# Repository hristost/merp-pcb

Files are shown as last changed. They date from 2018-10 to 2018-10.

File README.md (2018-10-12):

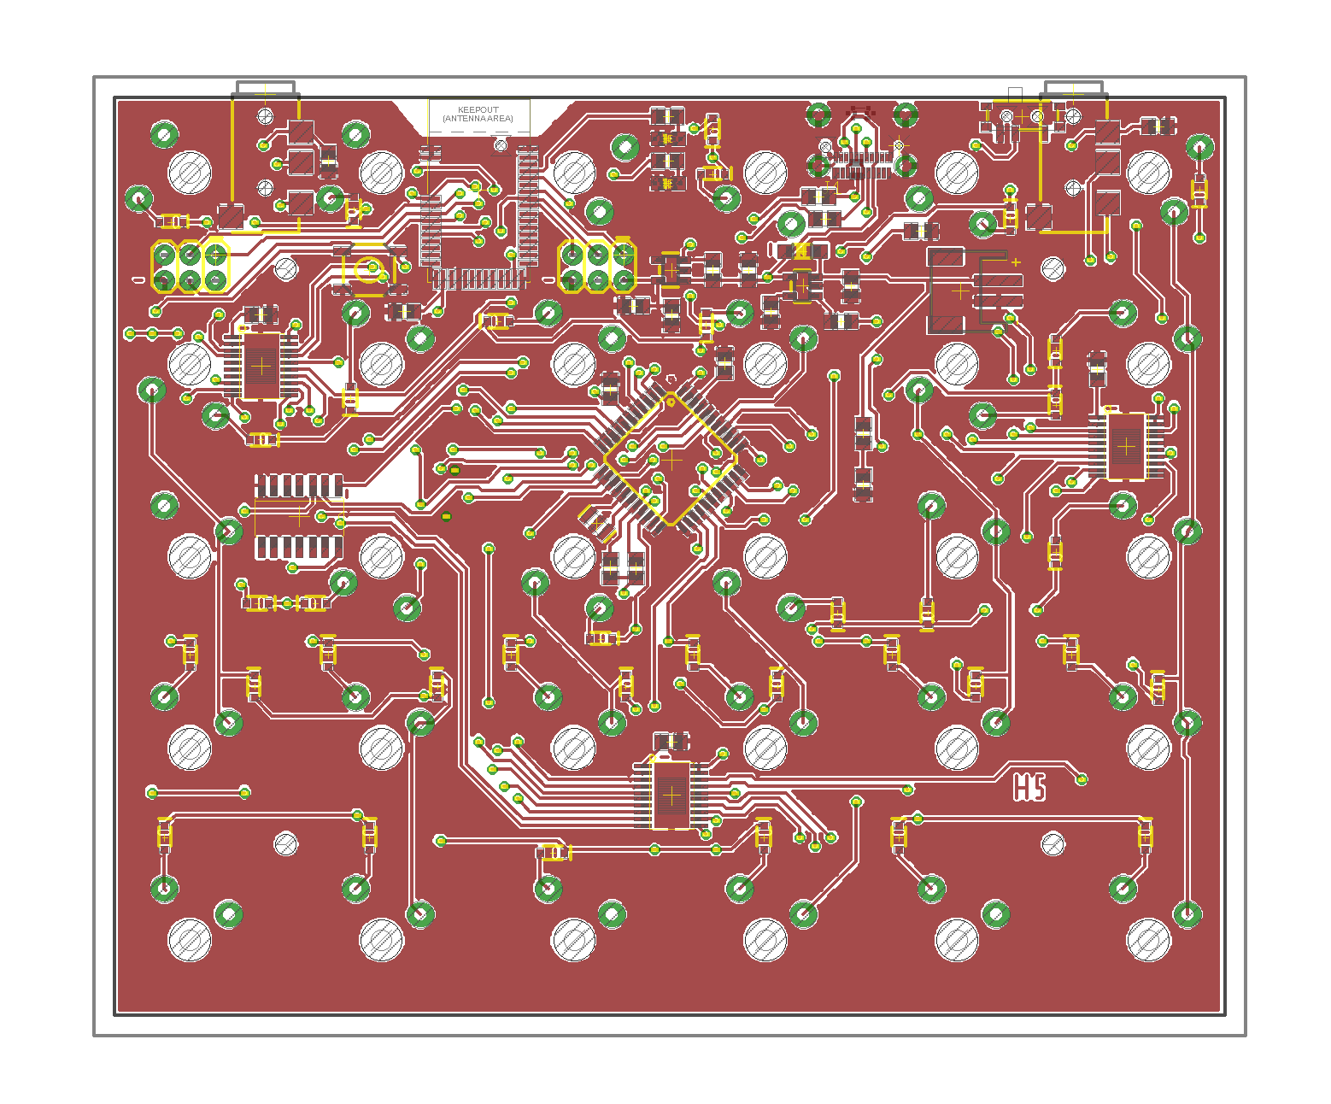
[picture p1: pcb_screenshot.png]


This is a PCB for a bluetooth split 12x5 ortholinear keyboard:
* Based on Adafruit's 32u4 
[Feather](https://github.com/adafruit/Adafruit-Feather-32u4-Bluefruit-LE-PCB)
beard. 
* Wireless (BLE) and wired (USB-C) mode.
* LED backlight.
* There are two 6x2 halves with identical PCBs. The _master_ half runs the QMK
firmware, and handles USB, BLE and battery charging. The _slave_ half is
responsible for only reporting its state to _master_ over I2C.
* Extra TRRS jack on the _slave_ half, making it possible to chain other I2C 
peripherals (think pedals).
* The board is flashed with the QMK firmware -- see my
[fork](https://github.com/hristost/qmk_firmware/tree/hristost_merp/keyboards/merp)
.

## Bluetooth
The PCB uses the Raytac MDBT-40 module for bluetooth. QMK has built-in support
for that module when flashed with Adafruit's 
[SPIFriend](https://github.com/adafruit/Adafruit_BluefruitLE_Firmware) firmware.

Since the Bluetooth module connects to the SPI bus, remember to flash the CPU
_before_ the Bluetooth module. Otherwise, the SPI bus will be taken and ICSP 
won't work.

## LED backlight
This keyboard has LED backlight, however:
* The drivers I used (TLC59711) draw quite some current on stand-by that makes
them unsuitable for battery-powered devices. I chose them because I already had
some left over from a previous project.
* Since the keyboard is "borderless", some switches have been rotated so that
components can fit between them. As a result, the backlight is uneven and would
not be suitable for actual backlit keys.
* The two halves operate backlight independently as of now, so any advanced
animation would have to utilise the I2C bus.
    
## Known issues:
I designed this keyboard just for fun and as such it has some shortcomings:
* The BLE module is somewhat hard to come by -- Mouser has it but it was out of
stock the few times I checked. Moreover, the Adafruit firmware for it
is closed source and you can only download binary images.
* Power management could be a lot better. Moreover, the keyboeard does not 
really have a stand-by state, instead, there is a switch that simply cuts all
power from the battery.
* The BLE module has enough processing
power to handle everything the CPU does now, but can't quite run QMK as of now.
(Another reason for sticking with _32u4_ is that it can easily be programmed
over USB)

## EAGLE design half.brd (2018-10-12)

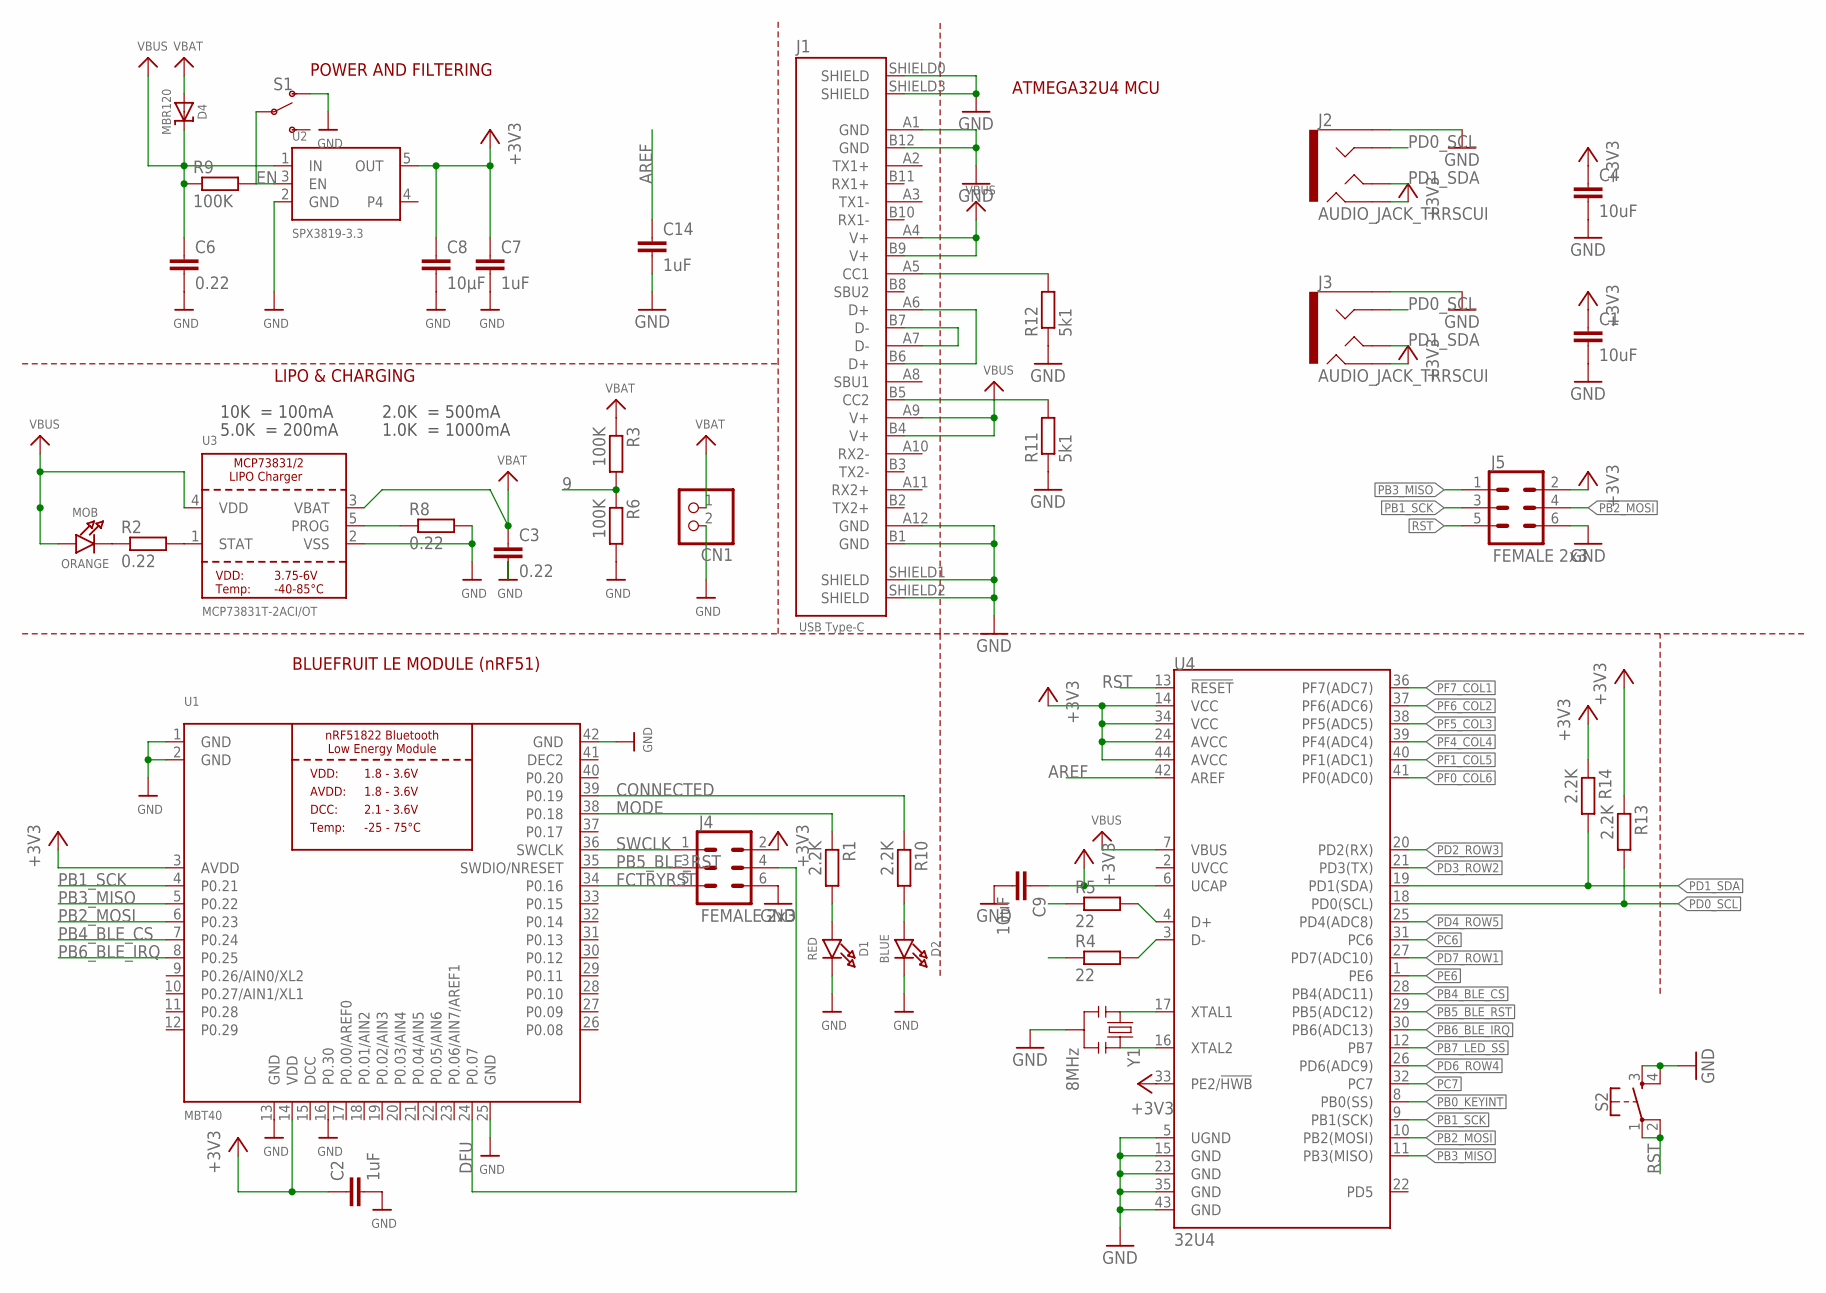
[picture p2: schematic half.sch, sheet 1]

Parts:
C1, C4, C9: 10uF; C0805
C2, C7, C14: 1uF; C0805
C3, C6: 0.22; C0805
C8: 10µF; C0805
CN1: JST_2PIN-SMT-RA; JST-PH-2-SMT-RA
D1: RED; CHIPLED_0805_NOOUTLINE
D2: BLUE; CHIPLED_0805_NOOUTLINE
D4: MBR120; SOD-123
J1: DX07S024JJ2_USB_TYPE-C; DX07S0224JJ2_USB-C
J2, J3: AUDIO_JACK_TRRSCUI; AUDIO_JACK_3.5MM_TRRS_SMD_CUI
J4, J5: FEMALE 2x3; 2X3
MOB: ORANGE; CHIPLED_0805_NOOUTLINE
R1, R10, R13, R14: 2.2K; R0805
R2, R8: 0.22; R0805
R3, R6, R9: 100K; R0805
R4, R5: 22; R0805
R11, R12: 5k1; R0805
S1: SWITCH-SPDT-SMD-RIGHT-ANGLE; SWITCH_SPST_SMD_A
S2: MOMENTARY-SWITCH-SPST-2-SMD-5.2MM; TACTILE_SWITCH_SMD_5.2MM
U1: MBT40; BLE_MODULE_RAYTAC_MDBT40
U2: SPX3819-3.3; SOT23-5
U3: MCP73831T-2ACI/OT; SOT23-5
U4: 32U4; TQFP44
Y1: 8MHz; RESONATOR-SMD

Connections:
9: R3.2, R6.1
+3V3: C1.1, C2.1, C4.1, C7.1, C8.1, C9.1, J2.RING2, J3.RING2, J4.2, J5.2, R13.1, R14.1, U1.3 (AVDD), U1.14 (VDD), U2.5 (OUT), U4.6 (UCAP), U4.14 (VCC), U4.24 (AVCC), U4.33 (PE2/!HWB), U4.34 (VCC), U4.44 (AVCC); also elsewhere on the board
AREF: C14.1, U4.42 (AREF)
CONNECTED: R10.1, U1.39 (P0.19)
D++: J1.A6 (D+), J1.B6 (D+), R5.1
D--: J1.A7 (D-), J1.B7 (D-), R4.1
DCC: U1.15 (DCC)
DEC2: U1.41 (DEC2)
DFU: J4.4, U1.24 (P0.07)
EN: R9.2, S1.2, U2.3 (EN)
FCTRYRST: J4.5, U1.34 (P0.16)
GND: C1.2, C2.2, C3.2, C4.2, C6.2, C7.2, C8.2, C9.2, C14.2, CN1.2 (1), D1.C, D2.C, J1.A1 (GND), J1.A12 (GND), J1.B1 (GND), J1.B12 (GND), J1.SHIELD0 (SHIELD), J1.SHIELD1 (SHIELD), J1.SHIELD2 (SHIELD), J1.SHIELD3 (SHIELD), J2.EARTH, J3.EARTH, J4.6, J5.6, R6.2, R8.2, R11.1, R12.1, S1.1 (O), S2.3, S2.4, U1.1 (GND), U1.2 (GND), U1.13 (GND), U1.16 (P0.30), U1.25 (GND), U1.42 (GND), U2.2 (GND), U3.2 (VSS), U4.5 (UGND), U4.15 (GND), U4.23 (GND), U4.35 (GND), U4.43 (GND), Y1.2; also elsewhere on the board
MODE: R1.1, U1.38 (P0.18)
unnamed: MOB.C, R2.1
unnamed: R2.2, U3.1 (STAT)
unnamed: R8.1, U3.5 (PROG)
unnamed: D1.A, R1.2
unnamed: D2.A, R10.2
unnamed: U4.17 (XTAL1), Y1.1
unnamed: U4.16 (XTAL2), Y1.3
unnamed: R5.2, U4.4 (D+)
unnamed: R4.2, U4.3 (D-)
unnamed: J1.A5 (CC1), R12.2
unnamed: J1.B5 (CC2), R11.2
PB0_KEYINT: U4.8 (PB0(SS)); also elsewhere on the board
PB1_SCK: J5.3, U1.4 (P0.21), U4.9 (PB1(SCK)); also elsewhere on the board
PB2_MOSI: J5.4, U1.6 (P0.23), U4.10 (PB2(MOSI)); also elsewhere on the board
PB3_MISO: J5.1, U1.5 (P0.22), U4.11 (PB3(MISO))
PB4_BLE_CS: U1.7 (P0.24), U4.28 (PB4(ADC11))
PB5_BLE_RST: J4.3, U1.35 (SWDIO/NRESET), U4.29 (PB5(ADC12))
PB6_BLE_IRQ: U1.8 (P0.25), U4.30 (PB6(ADC13))
PB7_LED_SS: U4.12 (PB7); also elsewhere on the board
PC6: U4.31 (PC6)
PC7: U4.32 (PC7)
PD0_SCL: J2.RING1, J3.RING1, R13.2, U4.18 (PD0(SCL))
PD1_SDA: J2.TIP, J3.TIP, R14.2, U4.19 (PD1(SDA))
PD2_ROW3: U4.20 (PD2(RX)); also elsewhere on the board
PD3_ROW2: U4.21 (PD3(TX)); also elsewhere on the board
PD4_ROW5: U4.25 (PD4(ADC8)); also elsewhere on the board
PD6_ROW4: U4.26 (PD6(ADC9)); also elsewhere on the board
PD7_ROW1: U4.27 (PD7(ADC10)); also elsewhere on the board
PE6: U4.1 (PE6)
PF0_COL6: U4.41 (PF0(ADC0)); also elsewhere on the board
PF1_COL5: U4.40 (PF1(ADC1)); also elsewhere on the board
PF4_COL4: U4.39 (PF4(ADC4)); also elsewhere on the board
PF5_COL3: U4.38 (PF5(ADC5)); also elsewhere on the board
PF6_COL2: U4.37 (PF6(ADC6)); also elsewhere on the board
PF7_COL1: U4.36 (PF7(ADC7)); also elsewhere on the board
RST: J5.5, S2.1, S2.2, U4.13 (!RESET)
SWCLK: J4.1, U1.36 (SWCLK)
VBAT: C3.1, CN1.1 (2), D4.A, R3.1, U3.3 (VBAT)
VBUS: C6.1, D4.C, J1.A4 (V+), J1.A9 (V+), J1.B4 (V+), J1.B9 (V+), MOB.A, R9.1, U2.1 (IN), U3.4 (VDD), U4.7 (VBUS)

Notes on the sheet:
POWER AND FILTERING
BLUEFRUIT LE MODULE (nRF51)
ATMEGA32U4 MCU
10K = 100mA
5.0K = 200mA
2.0K = 500mA
1.0K = 1000mA
LIPO & CHARGING

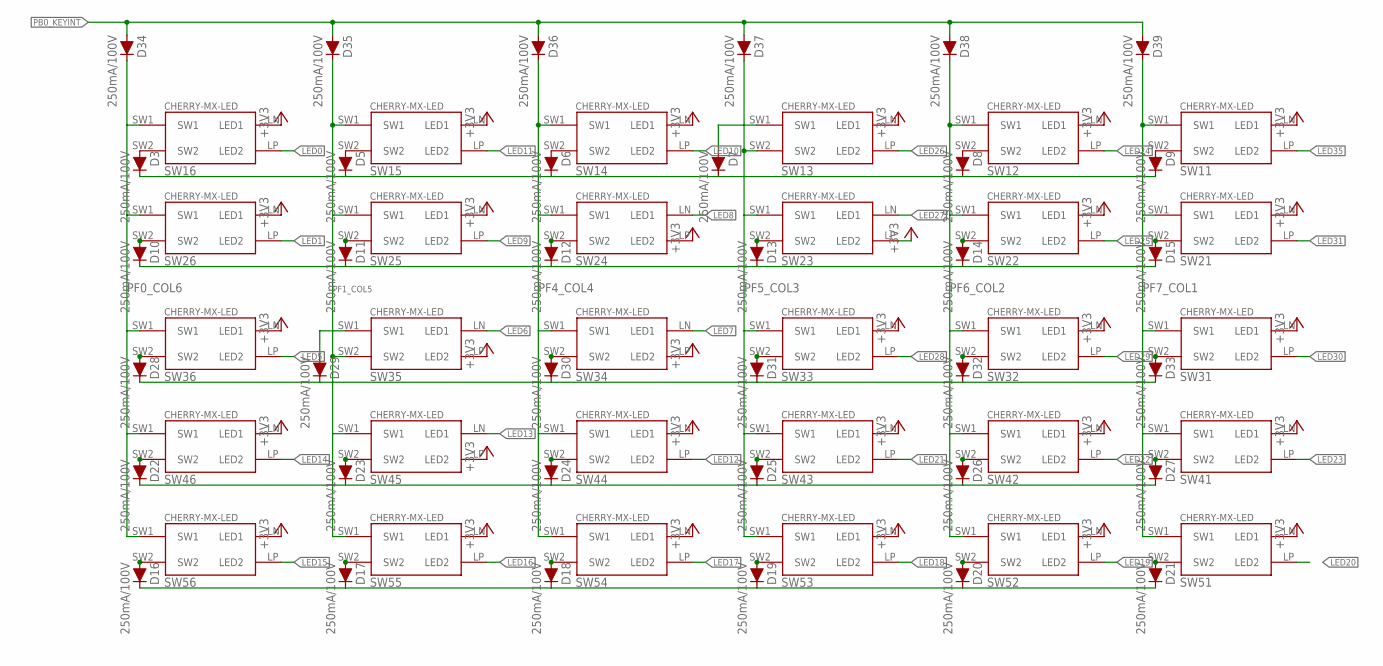
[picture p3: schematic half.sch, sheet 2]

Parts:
D3, D5, D6, D7, D8, D9, D10, D11, D12, D13, D14, D15, D16, D17, D18, D19, D20, D21, D22, D23, D24, D25, D26, D27, D28, D29, D30, D31, D32, D33, D34, D35, D36, D37, D38, D39: 250mA/100V; SOD-323
SW11, SW12, SW13, SW14, SW15, SW16, SW21, SW22, SW23, SW24, SW25, SW26, SW31, SW32, SW33, SW34, SW35, SW36, SW41, SW42, SW43, SW44, SW45, SW46, SW51, SW52, SW53, SW54, SW55, SW56: CHERRY-MX-LEDSMD; CHERRY-MX-PM-SMDLED

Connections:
+3V3: SW11.LN (LED1), SW12.LN (LED1), SW13.LN (LED1), SW14.LN (LED1), SW15.LN (LED1), SW16.LN (LED1), SW21.LN (LED1), SW22.LN (LED1), SW23.LP (LED2), SW24.LP (LED2), SW25.LN (LED1), SW26.LN (LED1), SW31.LN (LED1), SW32.LN (LED1), SW33.LN (LED1), SW34.LP (LED2), SW35.LP (LED2), SW36.LN (LED1), SW41.LN (LED1), SW42.LN (LED1), SW43.LN (LED1), SW44.LN (LED1), SW45.LP (LED2), SW46.LN (LED1), SW51.LN (LED1), SW52.LN (LED1), SW53.LN (LED1), SW54.LN (LED1), SW55.LN (LED1), SW56.LN (LED1); also elsewhere on the board
LED0: SW16.LP (LED2); also elsewhere on the board
LED1: SW26.LP (LED2); also elsewhere on the board
LED5: SW36.LP (LED2); also elsewhere on the board
LED6: SW35.LN (LED1); also elsewhere on the board
LED7: SW34.LN (LED1); also elsewhere on the board
LED8: SW24.LN (LED1); also elsewhere on the board
LED9: SW25.LP (LED2); also elsewhere on the board
LED10: SW14.LP (LED2); also elsewhere on the board
LED11: SW15.LP (LED2); also elsewhere on the board
LED12: SW44.LP (LED2); also elsewhere on the board
LED13: SW45.LN (LED1); also elsewhere on the board
LED14: SW46.LP (LED2); also elsewhere on the board
LED15: SW56.LP (LED2); also elsewhere on the board
LED16: SW55.LP (LED2); also elsewhere on the board
LED17: SW54.LP (LED2); also elsewhere on the board
LED18: SW53.LP (LED2); also elsewhere on the board
LED19: SW52.LP (LED2); also elsewhere on the board
LED20: SW51.LP (LED2); also elsewhere on the board
LED21: SW43.LP (LED2); also elsewhere on the board
LED22: SW42.LP (LED2); also elsewhere on the board
LED23: SW41.LP (LED2); also elsewhere on the board
LED24: SW12.LP (LED2); also elsewhere on the board
LED25: SW22.LP (LED2); also elsewhere on the board
LED26: SW13.LP (LED2); also elsewhere on the board
LED27: SW23.LN (LED1); also elsewhere on the board
LED28: SW33.LP (LED2); also elsewhere on the board
LED29: SW32.LP (LED2); also elsewhere on the board
LED30: SW31.LP (LED2); also elsewhere on the board
LED31: SW21.LP (LED2); also elsewhere on the board
LED35: SW11.LP (LED2); also elsewhere on the board
unnamed: D29.A, SW35.SW1
unnamed: D3.A, SW16.SW2
unnamed: D5.A, SW15.SW2
unnamed: D6.A, SW14.SW2
unnamed: D7.A, SW13.SW1
unnamed: D8.A, SW12.SW2
unnamed: D9.A, SW11.SW2
unnamed: D10.A, SW26.SW2
unnamed: D11.A, SW25.SW2
unnamed: D12.A, SW24.SW2
unnamed: D13.A, SW23.SW2
unnamed: D14.A, SW22.SW2
unnamed: D15.A, SW21.SW2
unnamed: D16.A, SW56.SW2
unnamed: D17.A, SW55.SW2
unnamed: D18.A, SW54.SW2
unnamed: D19.A, SW53.SW2
unnamed: D20.A, SW52.SW2
unnamed: D21.A, SW51.SW2
unnamed: D22.A, SW46.SW2
unnamed: D23.A, SW45.SW2
unnamed: D24.A, SW44.SW2
unnamed: D25.A, SW43.SW2
unnamed: D26.A, SW42.SW2
unnamed: D27.A, SW41.SW2
unnamed: D28.A, SW36.SW2
unnamed: D30.A, SW34.SW2
unnamed: D31.A, SW33.SW2
unnamed: D32.A, SW32.SW2
unnamed: D33.A, SW31.SW2
PB0_KEYINT: D34.A, D35.A, D36.A, D37.A, D38.A, D39.A; also elsewhere on the board
PD2_ROW3: D28.C, D29.C, D30.C, D31.C, D32.C, D33.C; also elsewhere on the board
PD3_ROW2: D10.C, D11.C, D12.C, D13.C, D14.C, D15.C; also elsewhere on the board
PD4_ROW5: D16.C, D17.C, D18.C, D19.C, D20.C, D21.C; also elsewhere on the board
PD6_ROW4: D22.C, D23.C, D24.C, D25.C, D26.C, D27.C; also elsewhere on the board
PD7_ROW1: D3.C, D5.C, D6.C, D7.C, D8.C, D9.C; also elsewhere on the board
PF0_COL6: D34.C, SW16.SW1, SW26.SW1, SW36.SW1, SW46.SW1, SW56.SW1; also elsewhere on the board
PF1_COL5: D35.C, SW15.SW1, SW25.SW1, SW35.SW2, SW45.SW1, SW55.SW1; also elsewhere on the board
PF4_COL4: D36.C, SW14.SW1, SW24.SW1, SW34.SW1, SW44.SW1, SW54.SW1; also elsewhere on the board
PF5_COL3: D37.C, SW13.SW2, SW23.SW1, SW33.SW1, SW43.SW1, SW53.SW1; also elsewhere on the board
PF6_COL2: D38.C, SW12.SW1, SW22.SW1, SW32.SW1, SW42.SW1, SW52.SW1; also elsewhere on the board
PF7_COL1: D39.C, SW11.SW1, SW21.SW1, SW31.SW1, SW41.SW1, SW51.SW1; also elsewhere on the board

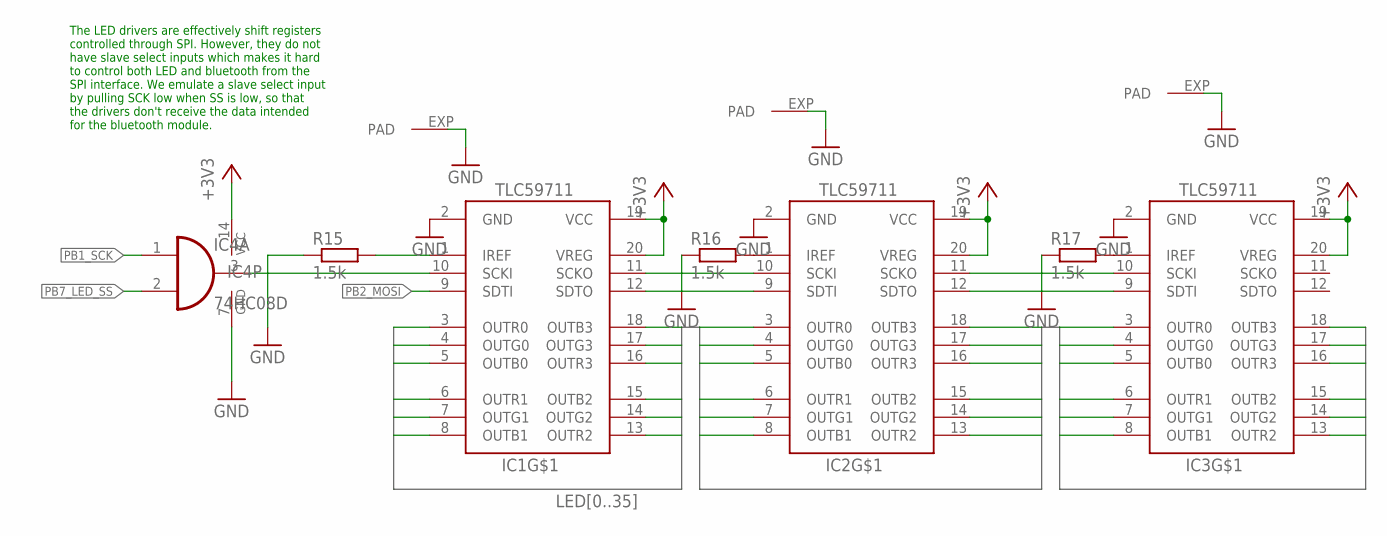
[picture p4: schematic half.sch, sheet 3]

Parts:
IC1, IC2, IC3: TLC59711; HTSSOP20DAP
IC4: 74HC08D; SO14
R15, R16, R17: 1.5k; R0805

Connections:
+3V3: IC1.19 (VCC), IC1.20 (VREG), IC2.19 (VCC), IC2.20 (VREG), IC3.19 (VCC), IC3.20 (VREG), IC4.14 (VCC); also elsewhere on the board
GND: IC1.2 (GND), IC1.EXP (PAD), IC2.2 (GND), IC2.EXP (PAD), IC3.2 (GND), IC3.EXP (PAD), IC4.7 (GND), R15.1, R16.1, R17.1; also elsewhere on the board
LED0: IC1.3 (OUTR0); also elsewhere on the board
LED1: IC1.4 (OUTG0); also elsewhere on the board
LED2: IC1.5 (OUTB0)
LED3: IC1.6 (OUTR1)
LED4: IC1.7 (OUTG1)
LED5: IC1.8 (OUTB1); also elsewhere on the board
LED6: IC1.13 (OUTR2); also elsewhere on the board
LED7: IC1.14 (OUTG2); also elsewhere on the board
LED8: IC1.15 (OUTB2); also elsewhere on the board
LED9: IC1.16 (OUTR3); also elsewhere on the board
LED10: IC1.17 (OUTG3); also elsewhere on the board
LED11: IC1.18 (OUTB3); also elsewhere on the board
LED12: IC2.3 (OUTR0); also elsewhere on the board
LED13: IC2.4 (OUTG0); also elsewhere on the board
LED14: IC2.5 (OUTB0); also elsewhere on the board
LED15: IC2.6 (OUTR1); also elsewhere on the board
LED16: IC2.7 (OUTG1); also elsewhere on the board
LED17: IC2.8 (OUTB1); also elsewhere on the board
LED18: IC2.13 (OUTR2); also elsewhere on the board
LED19: IC2.14 (OUTG2); also elsewhere on the board
LED20: IC2.15 (OUTB2); also elsewhere on the board
LED21: IC2.16 (OUTR3); also elsewhere on the board
LED22: IC2.17 (OUTG3); also elsewhere on the board
LED23: IC2.18 (OUTB3); also elsewhere on the board
LED24: IC3.3 (OUTR0); also elsewhere on the board
LED25: IC3.4 (OUTG0); also elsewhere on the board
LED26: IC3.5 (OUTB0); also elsewhere on the board
LED27: IC3.6 (OUTR1); also elsewhere on the board
LED28: IC3.7 (OUTG1); also elsewhere on the board
LED29: IC3.8 (OUTB1); also elsewhere on the board
LED30: IC3.13 (OUTR2); also elsewhere on the board
LED31: IC3.14 (OUTG2); also elsewhere on the board
LED32: IC3.15 (OUTB2)
LED33: IC3.16 (OUTR3)
LED34: IC3.17 (OUTG3)
LED35: IC3.18 (OUTB3); also elsewhere on the board
LEDDAT2: IC1.12 (SDTO), IC2.9 (SDTI)
LEDDAT3: IC2.12 (SDTO), IC3.9 (SDTI)
LEDSCK1: IC1.10 (SCKI), IC4.3 (O)
LEDSCK2: IC1.11 (SCKO), IC2.10 (SCKI)
LEDSCK3: IC2.11 (SCKO), IC3.10 (SCKI)
unnamed: IC1.1 (IREF), R15.2
unnamed: IC3.1 (IREF), R17.2
unnamed: IC2.1 (IREF), R16.2
PB1_SCK: IC4.1 (I0); also elsewhere on the board
PB2_MOSI: IC1.9 (SDTI); also elsewhere on the board
PB7_LED_SS: IC4.2 (I1); also elsewhere on the board

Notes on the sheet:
The LED drivers are effectively shift registers controlled through SPI. However, they do not have slave select inputs which makes it hard to control both LED and bluetooth from the SPI interface. We emulate a slave select input by pulling SCK low when SS is low, so that the drivers don't receive th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

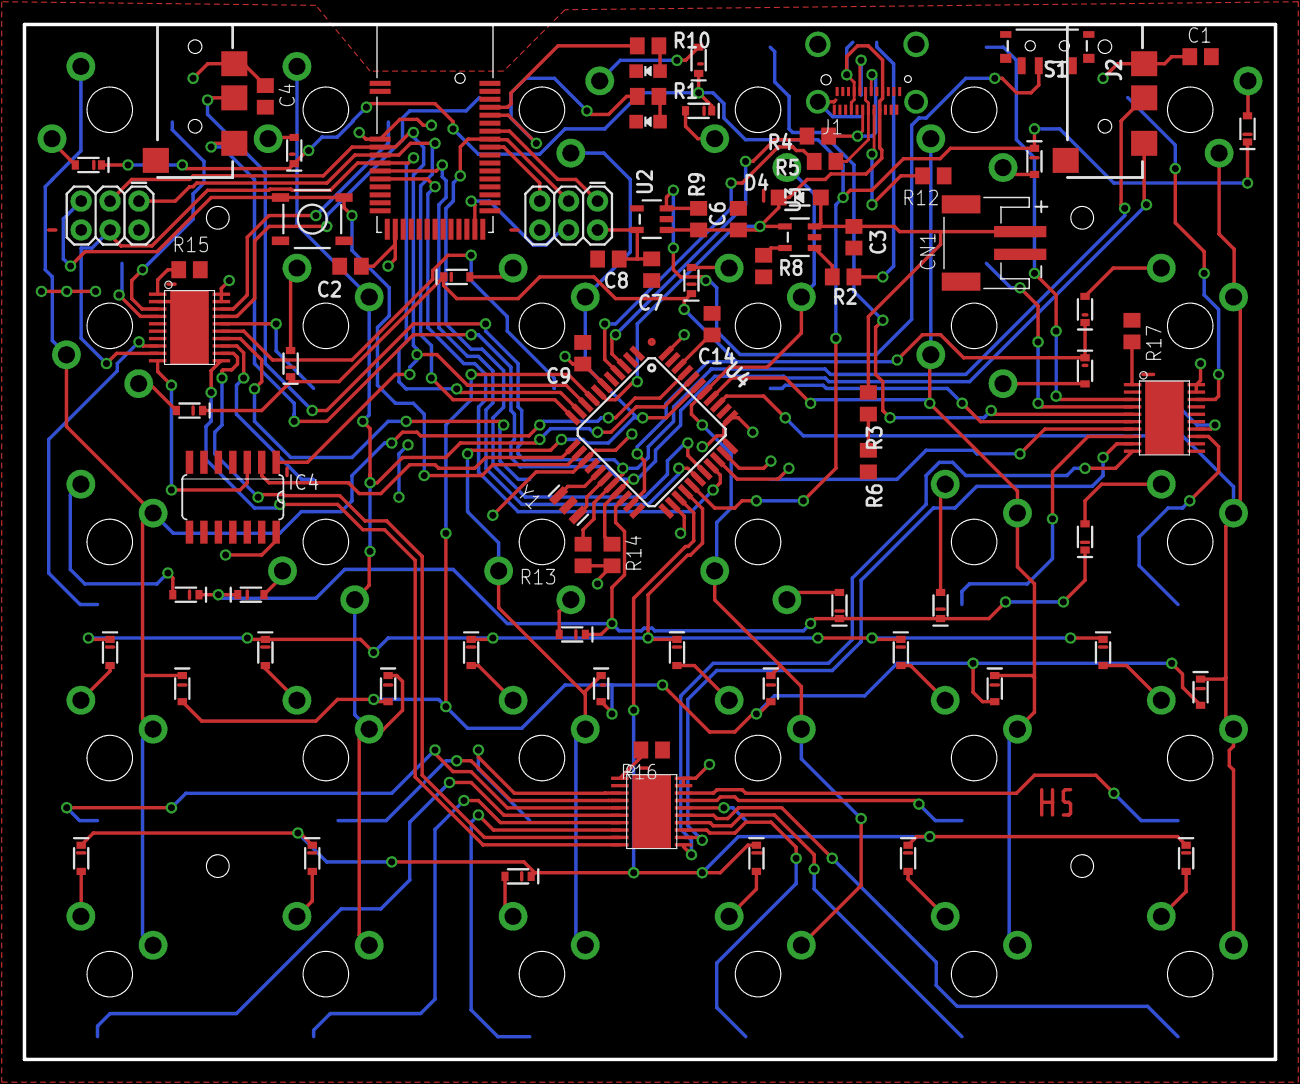
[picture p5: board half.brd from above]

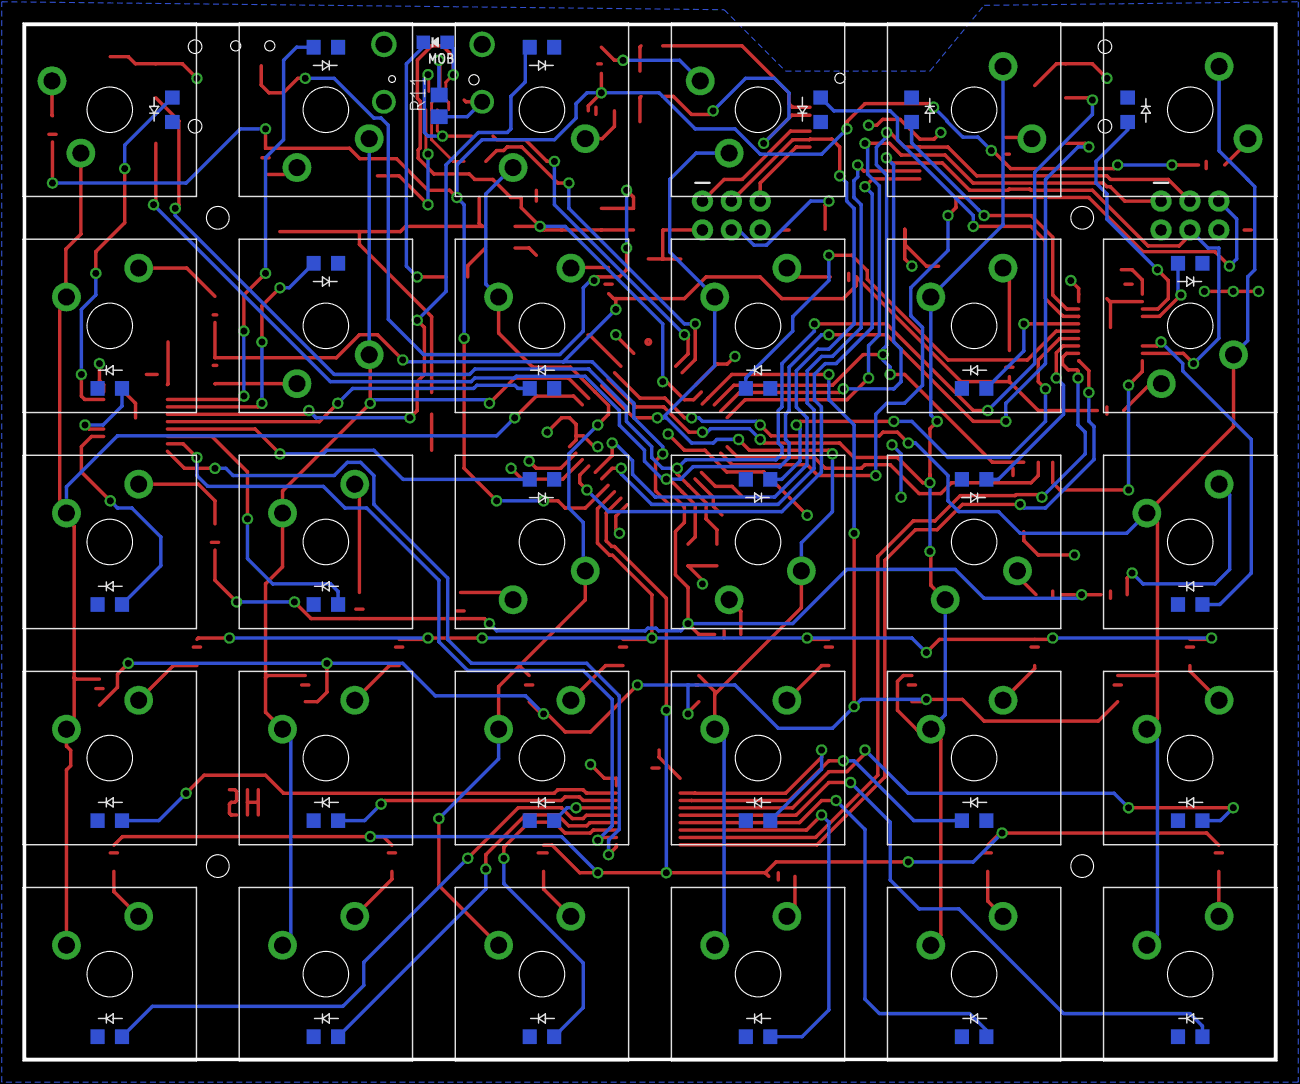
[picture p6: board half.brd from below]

Board: 2 copper layers, 110.0 x 91.0 mm, 112 parts (32 on the bottom side), 115 nets.

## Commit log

2018-10-12 Inital commit
    [half.brd, half.sch]
2018-10-12 Disconnect UVCC on 32u4 to reflect a greenwire fix on PCB
    [half.brd, half.sch]

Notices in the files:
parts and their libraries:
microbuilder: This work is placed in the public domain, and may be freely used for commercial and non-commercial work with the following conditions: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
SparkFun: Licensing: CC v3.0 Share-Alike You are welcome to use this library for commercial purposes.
